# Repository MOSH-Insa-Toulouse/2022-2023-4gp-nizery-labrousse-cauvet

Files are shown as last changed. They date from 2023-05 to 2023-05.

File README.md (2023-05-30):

# *PROJET CAPTEUR - CG-4127-GAF*

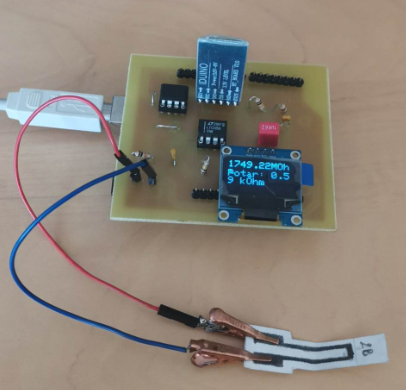
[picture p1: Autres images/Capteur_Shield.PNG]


## Introduction : Description du projet, Cahier des charges et Livrables 

Ce projet s’inscrit dans l’UF “Du capteur au banc de test” de 4ème année de Génie Physique de l’INSA Toulouse. Il s’inscrit dans une démarche low-tech de développement d’un capteur de contrainte et d’un système de mesure permettant la caractérisation du capteur. Il s’appuie sur l’étude de capteurs de contrainte en graphite (système granulaire) dont la résistance varie suivant la déformation du capteur (Pencil Drawn Strain Gauges and Chemiresistors on Paper Cheng-Wei Lin*, Zhibo Zhao*, Jaemyung Kim & Jiaxing Huang Department of Materials Science and Engineering, Northwestern University 2220 Campus Drive, Evanston, IL, 60208, USA).  
Ce travail comprend le design et la fabrication d’un shield Arduino incluant le capteur graphite couplé à un circuit analogique communiquant via un microcontrôleur à une application Android.
Dans un premier temps, nous avons simulé le comportement du circuit analogique sur le logiciel LTSpice. Ce circuit a le double rôle d’amplifier (via un amplificateur transimpédance) et de filtrer le signal délivré par le capteur.  
Ensuite, nous avons réalisé un code Arduino permettant la mesure de résistance et le contrôle des différents éléments du circuit (écran OLED, module Bluetooth et potentiomètre digital). Nous avons préalablement testé notre circuit et le code en montant les différents éléments sur une breadboard, puis nous avons designé un PCB grâce au logiciel KiCad constituant le shield se fixant sur une carte Arduino UNO.  
Après tirage du PCB, nous avons soudé l’ensemble des composants du circuit et développé une application Android sur le site MIT App Inventor affichant les mesures de résistance via transmission Bluetooth.  
Enfin, nous avons réalisé une datasheet caractérisant le capteur pour différents types de crayons graphites en mesurant la variation de résistance relative en fonction de la déformation du capteur grâce à un banc de mesure existant fabriqué en impression 3D.

### Livrables

Les livrables pour ce projet sont :

* Un shield PCB se fixant à une carte Arduino UNO comprenant un amplificateur transimpédance, un module Bluetooth, un écran OLED et un potentiomètre digital.
* Un code Arduino gérant la mesure de résistance du capteur graphite, la communication avec le module Bluetooth, l'affichage à l'écran OLED et la gestion du potentiomètre digital.
* Un Android APK qui gère l'interfaçage du système de mesure sur un téléphone Android.
* La datasheet du capteur de contrainte graphite.

## Matériel nécessaire
* 1 carte Arduino Uno
* 2 Résistance de 100kΩ
* 1 Résistance de 1kΩ
* 1 Potentiomètre digital MCP-41050
* 2 Condensateurs 100nF
* 1 Condensateurs 1µF
* 1 AOP LTC1050
* 1 Écran OLED01
* 1 Module Bluetooth HC-05

## Simulation du circuit transimpédance avec le logiciel LTSpice 

Nous avons réalisé la simulation électrique du circuit associé au shield sur le logiciel LTSpice. Voici le schéma du circuit simulé : 

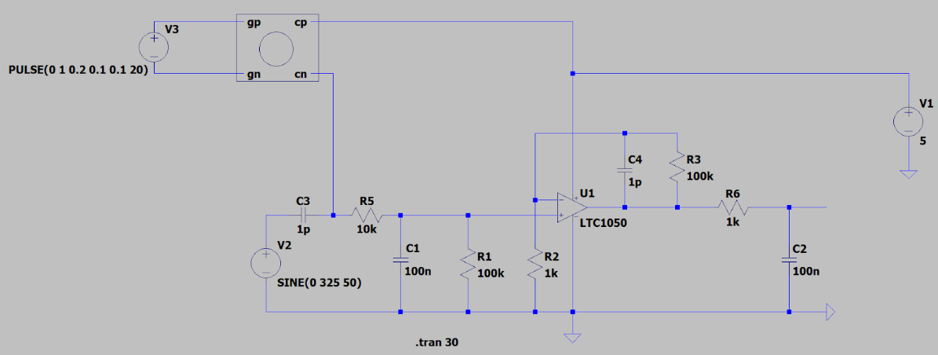
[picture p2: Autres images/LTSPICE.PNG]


Le capteur de graphite délivre un courant de 100 nA qui représente un signal trop faible pour que le microcontrôleur de la carte Arduino détecte les variations du signal. L’amplificateur transimpédance permet donc de transformer le signal de courant en tension et de l’amplifier. Le circuit est ensuite constitué de divers filtres permettant d’atténuer le bruit lié à l'environnement de la mesure (50Hz, hautes fréquences…).
Plusieurs tests ont été effectués sur le circuit et sur les filtres pour connaître le rôle de chacun d’eux et vérifier sa compatibilité avec la carte Arduino qui gère l’acquisition des données.

## Code arduino

Le code .ino donne les instructions à l’arduino pour traiter les informations reçues par le capteur graphite et pour envoyer les informations au module bluetooth HC-05 qui communique avec l’application APK, au potentiomètre digital ainsi qu’à l’écran OLED. Différentes bibliothèques sont incluses, la bibliothèque Adafruit_SSD1306 permet de faciliter la communication avec l’écran OLED, la bibliothèque SPI nous permet d’écrire au potentiomètre digital ses nouvelles valeurs au besoin, SoftwareSerial gère la communication avec l’appareil bluetooth HC-05. Le code de l’arduino permet donc plusieurs choses : 
* Calculer la résistance du capteur graphite en temps réel
* Modifier la valeur de la résistance du potentiomètre digital, ce qui nous permet de régler la sensibilité de la mesure, ainsi que de capter des signaux dans l’intervalle de bits [0:1023] dans lequel l’arduino est limité.
* Afficher la résistance du capteur graphite et la résistance du potentiomètre digital sur l’écran OLED
* Communiquer à l’application la valeur en bits du signal du capteur graphite en compressant sa valeur sur un byte, qui pourra être analysé par l’application APK.

## Création du PCB sur Kicad 

Cette partie du projet consistait à concevoir le PCB du circuit transimpédance sur le logiciel Kicad. En partant d’un template d’une carte Arduino Uno, il a fallu : 
* Concevoir la schématique du circuit transimpédance en créant des symboles pour les composants non existants dans la base de donnée du logiciel
* Concevoir les empreintes réelles de ces composants non existants en prenant en compte leurs caractéristiques physiques (nombres de pins, distance entre les pins, géométrie des empreintes…)
* Effectuer le routage du circuit à partir du chevelu implémenté grâce à la vue schématique du circuit
* Poser le plan de masse pour référencer les pistes au GND

Vous trouverez ci-dessous l’intégralité des symboles et empreintes créées ainsi que la vue schématique du circuit et le PCB final.

### Symboles et empreintes 

* Module Bluetooth HC-05

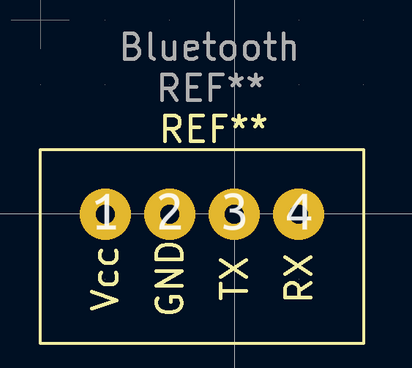
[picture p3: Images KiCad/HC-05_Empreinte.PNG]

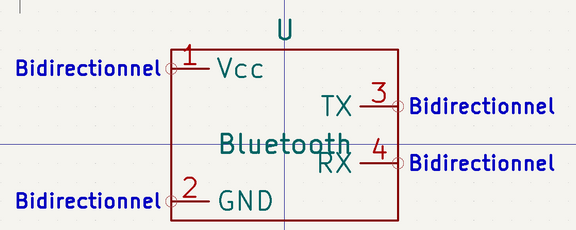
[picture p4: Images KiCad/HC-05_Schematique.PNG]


* Amplificateur LTC1050

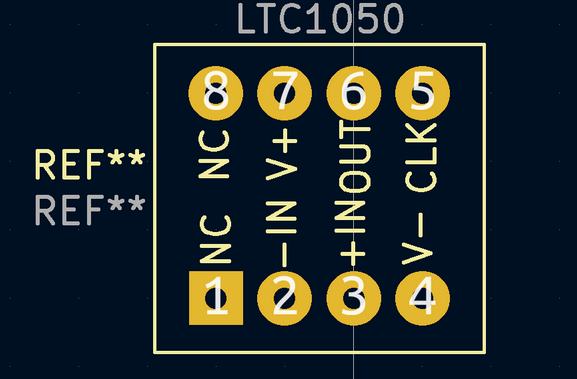
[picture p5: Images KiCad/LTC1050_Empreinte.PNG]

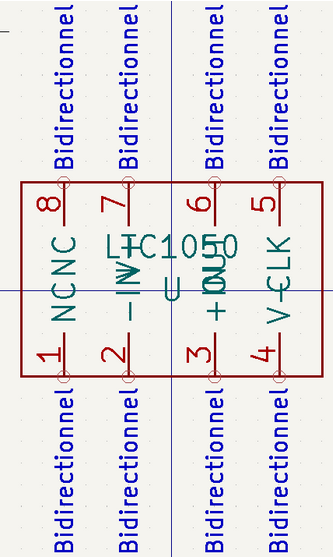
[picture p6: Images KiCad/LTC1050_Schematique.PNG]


* Ecran OLED

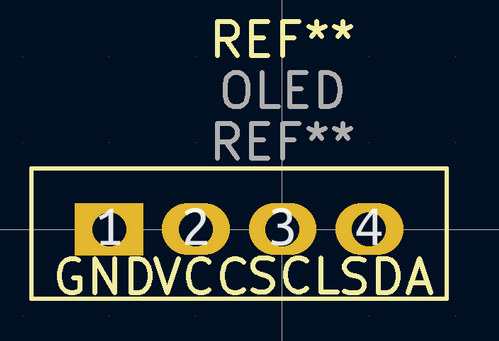
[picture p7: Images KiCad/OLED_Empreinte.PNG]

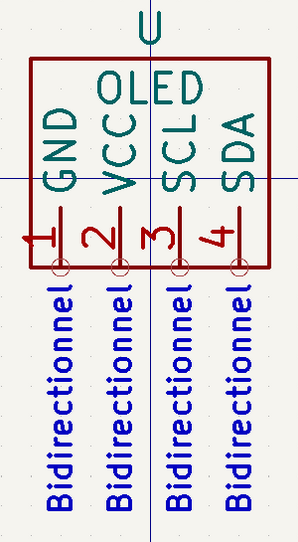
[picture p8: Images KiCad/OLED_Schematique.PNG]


* Potentiomètre digital MCP41050

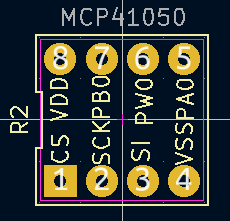
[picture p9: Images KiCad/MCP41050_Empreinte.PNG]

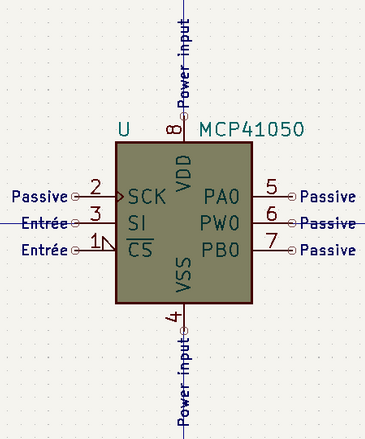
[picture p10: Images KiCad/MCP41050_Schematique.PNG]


### Schéma Complet

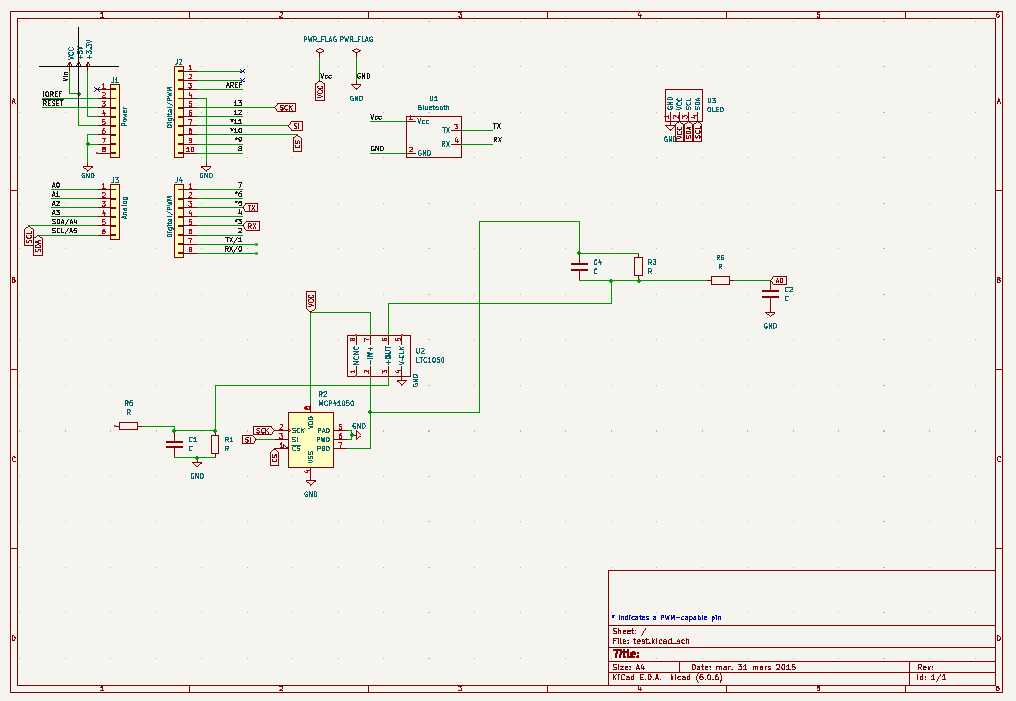
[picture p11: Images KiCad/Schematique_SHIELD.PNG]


### PCB

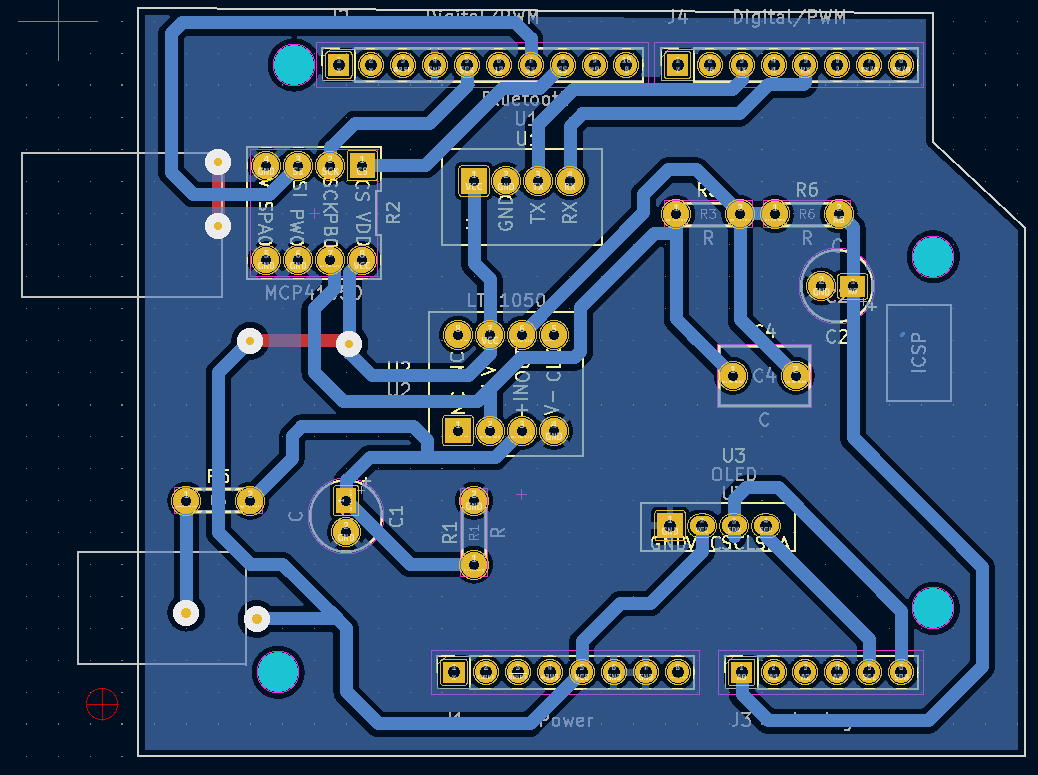
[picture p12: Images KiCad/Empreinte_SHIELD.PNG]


## Fabrication du Shield
 
### Réalisation PCB

Voici ci-dessus le circuit imprimé réalisé à partir d’un calque de PCB. 

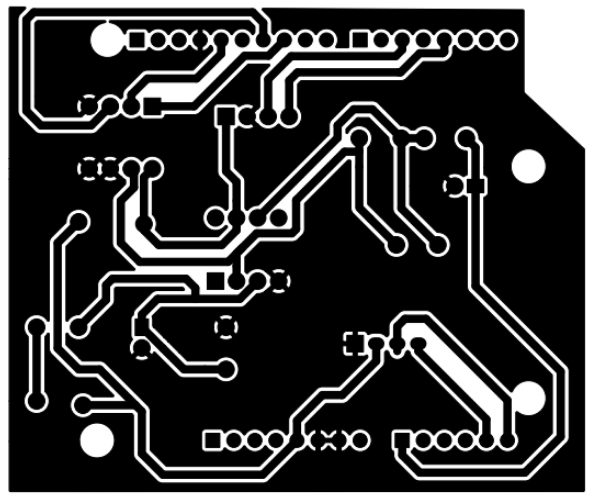
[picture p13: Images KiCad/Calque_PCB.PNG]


Le PCB a été réalisé au sein de deux départements de l’INSA Toulouse, le Génie Électrique et Informatique et le Génie Physique. Il a été fabriqué avec une plaquette d’époxy recouverte d’une couche de cuivre d’environ 60𝝻m. Nous avons imprimé sur du calque le circuit ci-dessus, puis nous avons insolé aux UVs notre plaquette avec ce calque pendant une dizaine de minutes. Après avoir retiré la partie de résine non isolée avec un révélateur, nous avons plongé notre plaquette dans un bain de percholorure de fer. Cela a permis de retirer le cuivre qui n’était pas protégé et de révéler les pistes de notre circuit.

### Perçage et soudures 

Une fois le PCB réalisé, il faut percer avec une perceuse électrique les trous pour y mettre les différents composants. Nous avons utilisé deux tailles de pointes pour percer les trous:
un de diamètre 0,8mm pour tous les différents composants et headers des modules OLED et Bluetooth
un de diamètre 1mm pour les broches de connexion de la carte Arduino Uno

Nous avons aussi dû percer deux trous pour y insérer un via pour relier deux points de masse (cela était prévu dans le schéma Kicad).

## Application téléphone APK

Nous avons développé une application Android à l’aide du site MIT App Inventor. Cette application permet de recevoir les données de la carte Arduino par connexion Bluetooth avec le module HC-05 implémenté sur le shield de la carte Arduino. Après connexion Bluetooth, un graphe se dessine permettant de suivre la résistance du capteur graphite en fonction du temps et des contraintes qui lui sont appliquées. La valeur de cette résistance est également affichée implicitement en plus de la valeur de la de résistance du potentiomètre digital.

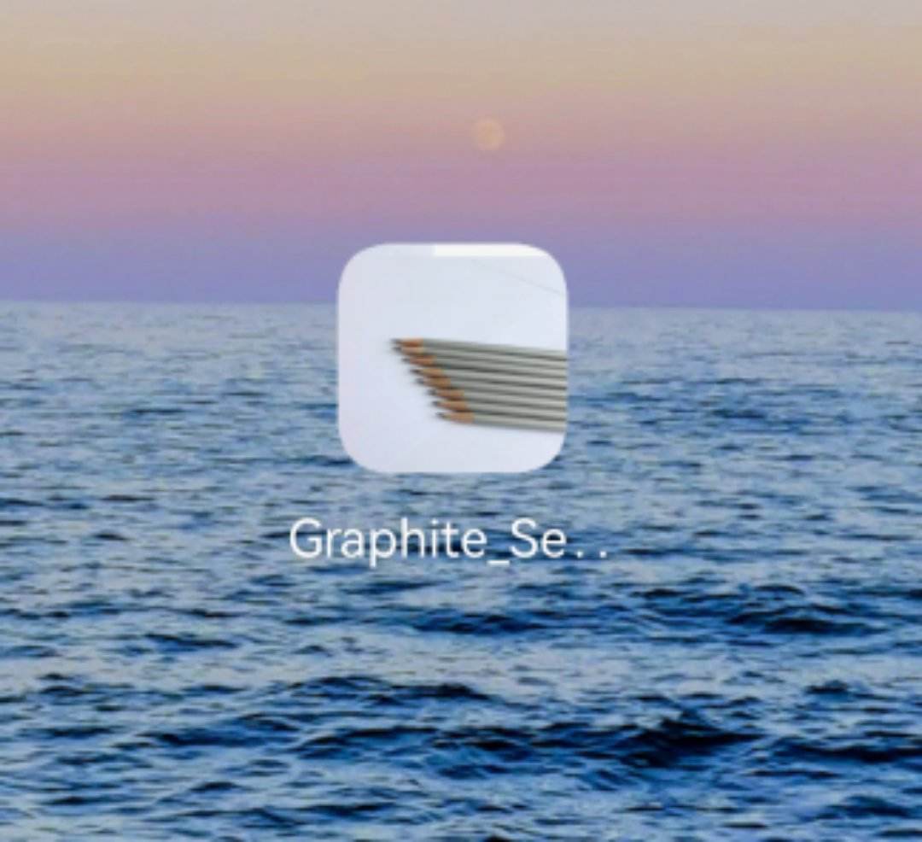
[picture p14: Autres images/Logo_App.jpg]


## Banc de test  

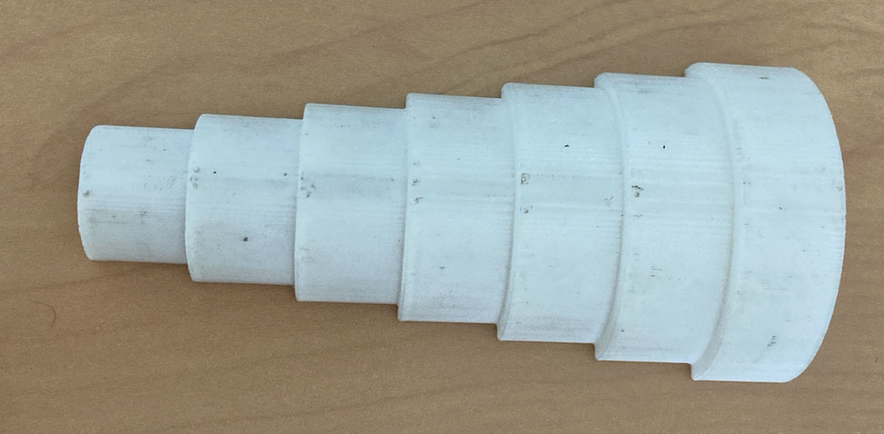
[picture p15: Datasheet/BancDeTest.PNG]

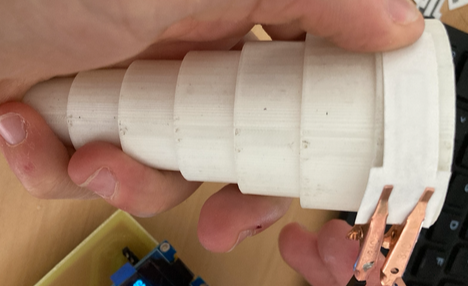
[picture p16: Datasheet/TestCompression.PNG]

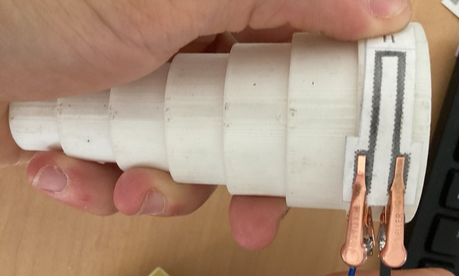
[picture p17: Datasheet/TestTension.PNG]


Nous utilisons ce banc de test composé de 7 demi cylindres de différents diamètres allant de 2 à 5 cm avec un pax de 0,5 cm. Nous posons le capteur sur chacun des cylindres et appliquons donc une déformation  sur celui-ci. Cette déformation se retrouve avec la formule ci-dessous : 
$$\epsilon = \frac{e}{2r}$$ 
avec e l’épaisseur du capteur et r le rayon de courbure donc le rayon de chaque demi cylindre.
Nous avons réalisé les mesures en compression et en tension pour chacun de nos capteurs.  

### Résultats obtenus

Vous retrouverez les résultats obtenus avec notre banc de test dans la datasheet [ici](Datasheet/Datasheet_CG-4127-GAF.docx).

### Analyse et pistes d’améliorations

Lors de nos mesures, nous devions reprendre le R0 à chaque essai car celui-ci augmentait entre-temps. Le papier trop fragile, s'abîmait et rendait plus difficile la conduction des électrons, la résistance augmente donc. Il serait donc envisageable de prendre un papier plus résistant qui ne se déformerait pas de manière permanente après chaque mesure.

On peut également penser à l'utilisation d'un dispositif à base d'un servomoteur, en remplacement de notre banc de test, car celui-ci nous permettrait de reproduire les expériences de manière plus fiable, avec tout le temps la même tension/compression exercée entre les différents capteurs.

Afin d'avoir une excellente sensibilité pour toutes les plages de résistance, on aurait pu augmenter le nombre de valeurs de résistance du potentiomètre qui se règlent automatiquement.

## Datasheet 

La datasheet de notre capteur est disponible dans le dossier Datasheet [ici](Datasheet/Datasheet_CG-4127-GAF.docx).

## *Auteurs*

Si vous avez des remarques ou questions complémentaires sur ce projet, n’hésitez pas à nous contacter :

Guillaume Cauvet : cauvet@insa-toulouse.fr  
Fabien Labrousse : labrousse@insa-toulouse.fr  
Audrey Nizery : nizery@insa-toulouse.fr

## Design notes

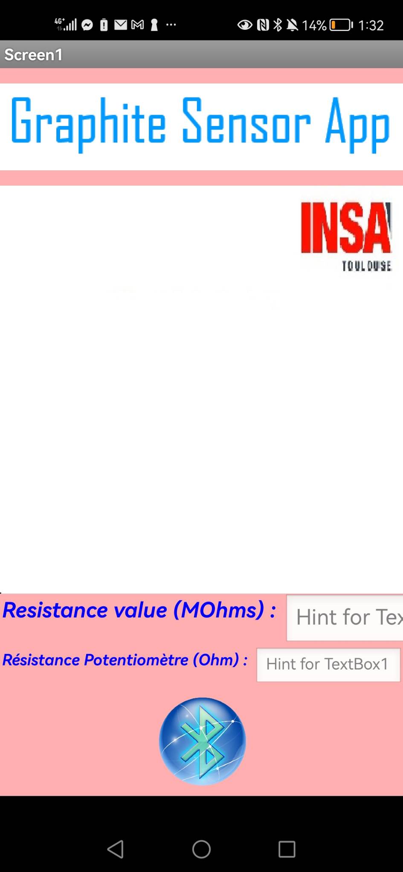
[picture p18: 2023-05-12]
APK Bluetooth/App_BT_CG-4127-GAF.jpg

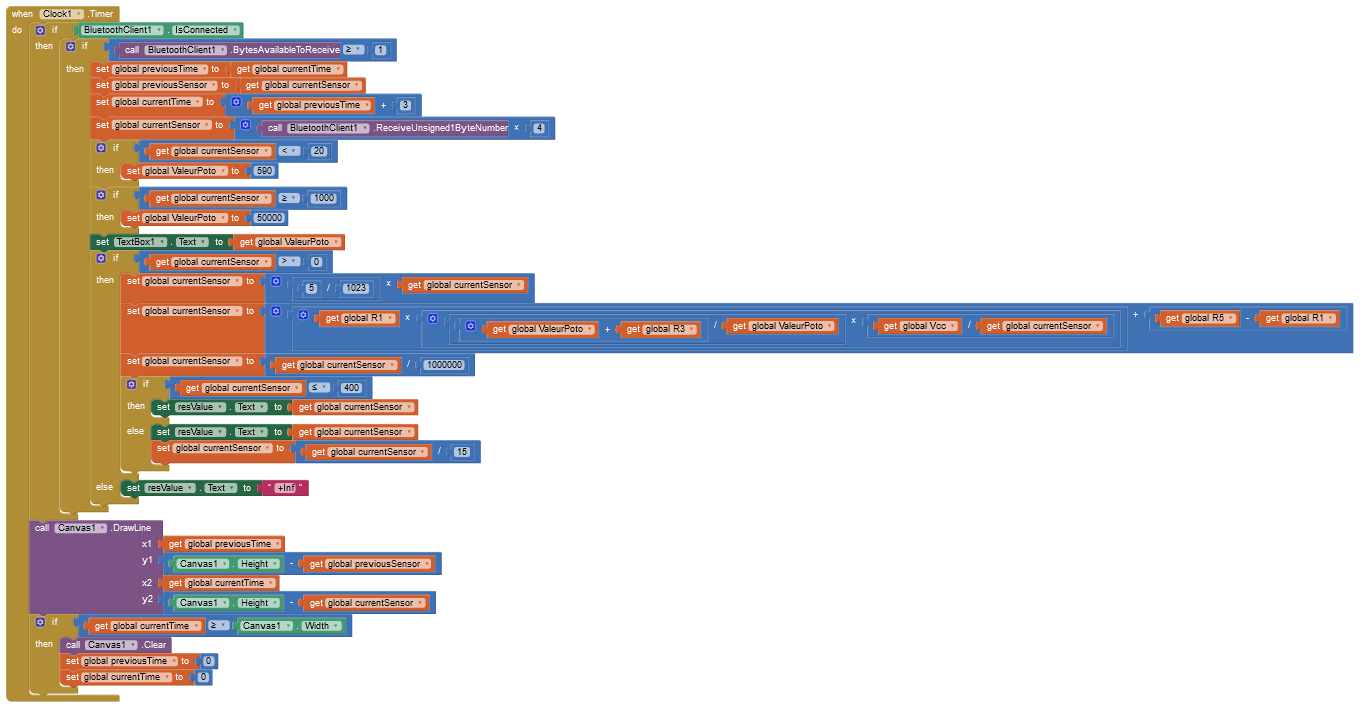
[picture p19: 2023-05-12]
APK Bluetooth/Code_Bluetooth_Part2.PNG

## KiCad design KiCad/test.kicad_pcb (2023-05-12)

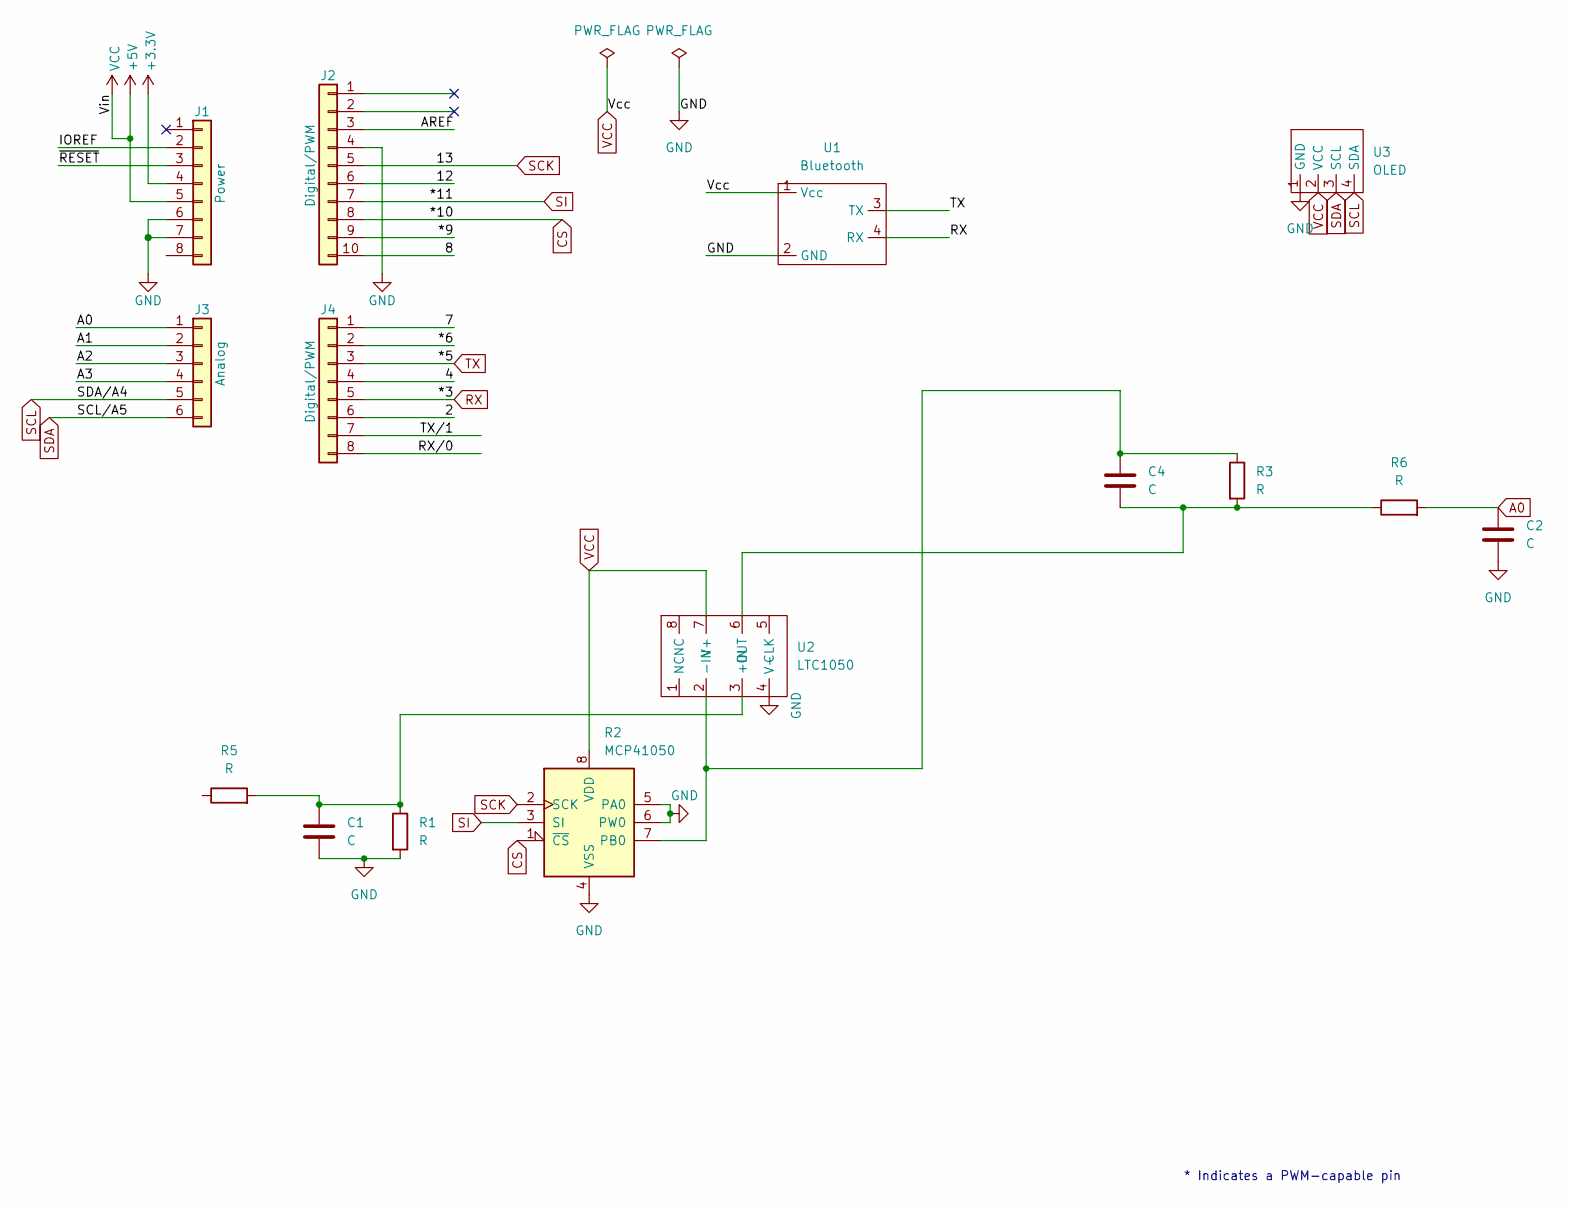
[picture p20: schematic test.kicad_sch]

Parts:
C1, C2: C; CP_Radial_Tantal_D5.5mm_P2.50mm
C4: C; C_Rect_L7.0mm_W4.5mm_P5.00mm
J1: Power; PinSocket_1x08_P2.54mm_Vertical
J2: Digital/PWM; PinSocket_1x10_P2.54mm_Vertical
J3: Analog; PinSocket_1x06_P2.54mm_Vertical
J4: Digital/PWM; PinSocket_1x08_P2.54mm_Vertical
R1, R3, R5, R6: R; R_Axial_DIN0204_L3.6mm_D1.6mm_P5.08mm_Horizontal
R2: MCP41050; Pot_Digital
U1: Bluetooth
U2: LTC1050
U3: OLED

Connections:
+3V3: J1.4
/2: J4.6
/4: J4.4
/7: J4.1
/8: J2.10
/12: J2.6
/*6: J4.2
/*9: J2.9
/A1: J3.2
/A2: J3.3
/A3: J3.4
/AREF: J2.3
/IOREF: J1.2
/RX/0: J4.8
/TX/1: J4.7
/~RESET: J1.3
A0: C2.1, J3.1, R6.2
CS: J2.8, R2.1 (~CS)
GND: C1.2, C2.2, J1.6, J1.7, J2.4, R1.2, R2.4 (VSS), R2.5 (PA0), R2.6 (PW0), U1.2 (GND), U2.4 (V-), U3.1 (GND)
unnamed: C1.1, R1.1, R5.2, U2.3 (+IN)
unnamed: C4.1, R2.7 (PB0), R3.1, U2.2 (-IN)
unnamed: C4.2, R3.2, R6.1, U2.6 (OUT)
RX: J4.5, U1.4 (RX)
SCK: J2.5, R2.2 (SCK)
SCL: J3.5, U3.4 (SDA)
SDA: J3.6, U3.3 (SCL)
SI: J2.7, R2.3 (SI)
TX: J4.3, U1.3 (TX)
VCC: J1.5, R2.8 (VDD), U1.1 (Vcc), U2.7 (V+), U3.2 (VCC)

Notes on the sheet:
* Indicates a PWM-capable pin

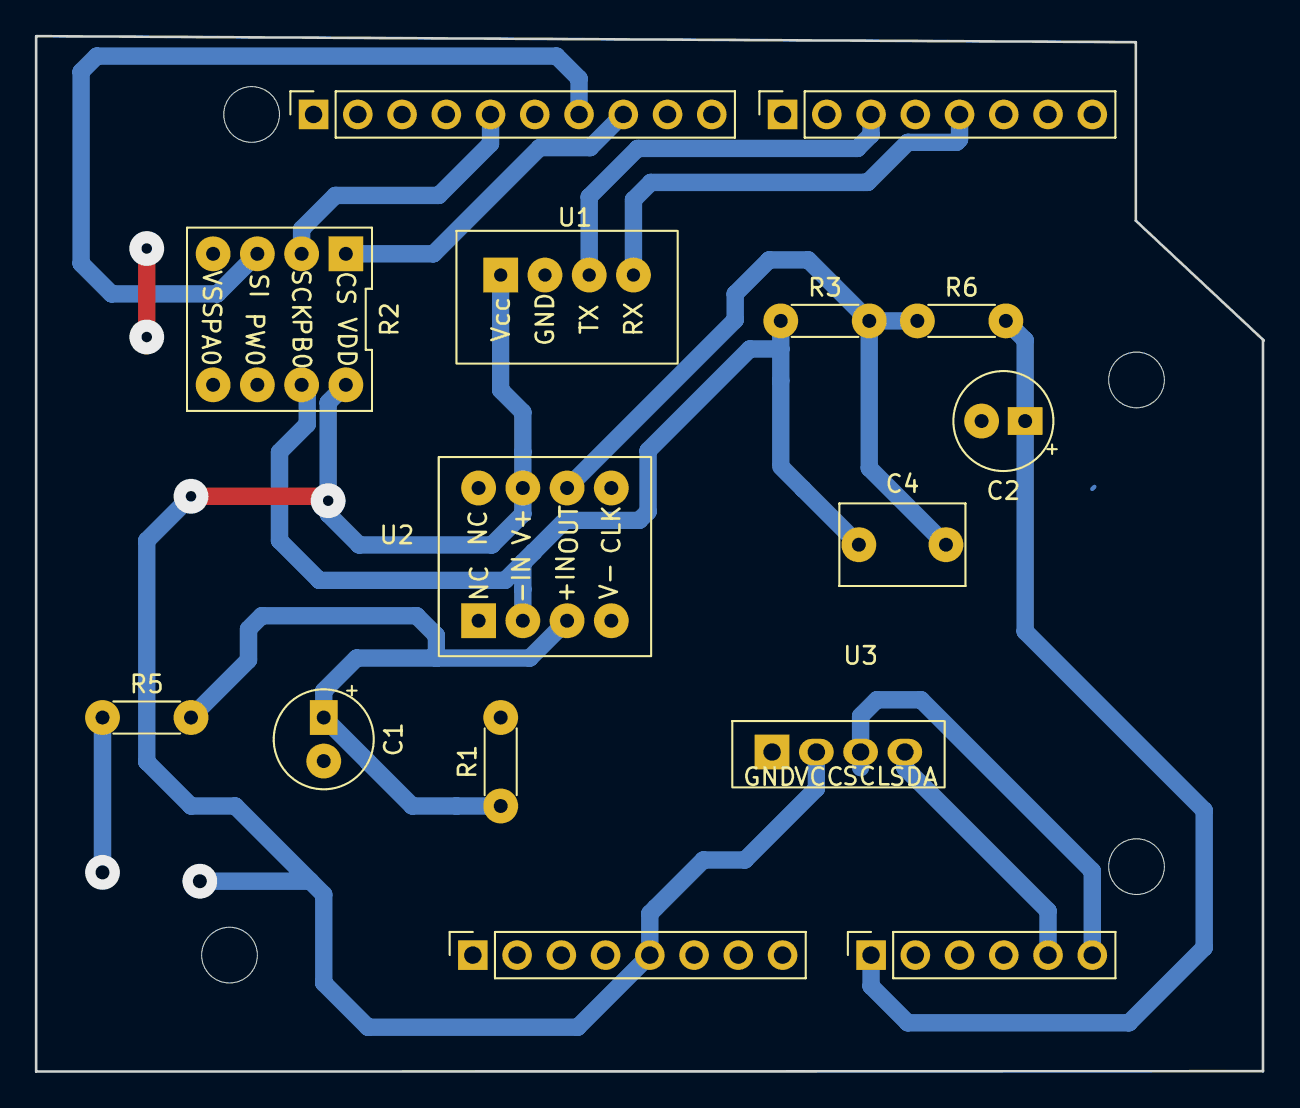
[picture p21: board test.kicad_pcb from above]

Board: 2 copper layers, 70.5 x 59.4 mm, 19 parts (0 on the bottom side), 13 nets.

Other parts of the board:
MH1, MH2, MH3, MH4: MountingHole_3.2mm

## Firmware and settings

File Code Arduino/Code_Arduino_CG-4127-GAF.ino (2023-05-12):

/////////////////// INCLUSION DES BIBLIOTHEQUES /////////////////////////

#include <Adafruit_SSD1306.h>               // Bibliothèque de l'écran OLED
#include <SPI.h>                            // Bibliothèque pour communiquer avec le potentiomètre digital
#include <SoftwareSerial.h>                 // Bibliothèque pour gérer la communication avec l'appareil bluetooth

/////////////////// DEFINITION DE PARAMETRES //////////////////////////

#define nombreDePixelsEnLargeur 128         // Taille de l'écran OLED, en pixel, au niveau de sa largeur
#define nombreDePixelsEnHauteur 64          // Taille de l'écran OLED, en pixel, au niveau de sa hauteur
#define brocheResetOLED         -1          // Reset de l'OLED partagé avec l'Arduino (d'où la valeur à -1, et non un numéro de pin)
#define adresseI2CecranOLED     0x3C        // Adresse de "mon" écran OLED sur le bus i2c (généralement égal à 0x3C ou 0x3D)
// Define the MCP41050 OP command bits (only one POT), potentiomètre 50kOhm max
// Note: command byte format xxCCxxPP, CC command, PP pot number (01 if selected) 
#define MCP_NOP 0b00000000
#define MCP_WRITE 0b00010001
#define MCP_SHTDWN 0b00100001
#define rxPin 5 // Broche 11 en tant que RX, raccordé sur TX du HC-05
#define txPin 3 // Broche 10 en tant que RX, raccordé sur TX du HC-05
#define baudrate 9600 // baudRate à 9600, identique à celui du moniteur série pour synchroniser la communication
SoftwareSerial mySerial(rxPin ,txPin); // Définition du software serial

const int ssMCPin = 10; // Define the slave select for the digital pot

Adafruit_SSD1306 ecranOLED(nombreDePixelsEnLargeur, nombreDePixelsEnHauteur, &Wire, brocheResetOLED); // On nomme ecranOLED la bibliothèque Adafruit pour
// gérer par la suite les commandes de l'écran OLED

////////////// DECLARATION DES VARIABLES /////////////////////////

const int Capteur = A0; // On initialise le capteur à l'entrée analogique A0
int ValeurResBit=80; // valeur de la résistance comprise entre 0 et 1023 bits
//uint8_t ValeurResbitAppli;
float ValeurResBitFloat; // Sert uniquement à récupérer la valeur de ResBit en float pour éviter des types avec le calcul de ValeurResTension
float ValeurResTension; // valeur de la résistance comprise entre 0 et 5V
float ValeurRes; // valeur de la résistance du capteur graphite en OhM
float ValeurPotoR2=255; // Le potentiomètre digital divise ses valeurs de résistance entre 0 et 50kOmh en un intervalle de 256 valeurs (sur 256 bits)
float ValeurPotoR2OLED; // valeur de la résistance R2 qu'on utilisera spécifiquement pour afficher la valeur de R2 sur l'écran OLED
float ValeurPotoR2Calculs; // valeur de la résistance R2 qu'on utilise pour les calculs, R2 est en Ohm ici
float R1=100000; //en Ohm
float R3=100000;
float R5=10000;
float R6=1000;
float Vcc=5; //en Volt

/////////////// FONCTION POUR ECRIRE AU POTENTIOMETRE DIGITAL ///////////////////////////////

void SPIWrite(uint8_t cmd, uint8_t data, uint8_t ssPin) // SPI write the command and data to the MCP IC connected to the ssPin, on s'en sert pour communiquer
//avec le potentiomètre digital
{
  SPI.beginTransaction(SPISettings(14000000, MSBFIRST, SPI_MODE0)); //https://www.arduino.cc/en/Reference/SPISettings
  data = constrain (data, 0, 255); //comme cette fonction sert à communiquer avec le potentiomètre digital qui est sur 256 bits, on restreint les valeurs
  //de la donnée entre 0 et 255, un intervalle entier de 256 valeurs, celles que peut prendre le potentiomètre digital
  digitalWrite(ssPin, LOW); // SS pin low to select chip
  
  SPI.transfer(cmd);        // Send command code
  SPI.transfer(data);       // Send associated value
  
  digitalWrite(ssPin, HIGH);// SS pin high to de-select chip
  SPI.endTransaction(); //à l'issu de toutes ces étapes, on termine la communication des données
}

///////////////////////// SETUP DU PROGRAMME ////////////////////////////////

void setup() {
  if(!ecranOLED.begin(SSD1306_SWITCHCAPVCC, adresseI2CecranOLED)) // On initialise l'écran OLED et on le prépare à communiquer dans le voidLoop
   while(1);   
  ecranOLED.clearDisplay(); // On clear l'écran avant de rentrer dans le corps du code
  pinMode(rxPin,INPUT); // On définit le pin Rx en INPUT
  pinMode(txPin,OUTPUT); // On définit le pin Tx en OUTPUT
  mySerial.begin(baudrate); // On définit le baudrate de la communication avec l'appareil bluetooth à 9600
  pinMode(Capteur,INPUT); // On définit l'entrée analogique A0 en INPUT, c'est celle qui va recevoir les valeurs de la résistance du capteur graphite
  pinMode (ssMCPin, OUTPUT); //select pin output
  digitalWrite(ssMCPin, HIGH); //SPI chip disabled
  SPI.begin();  
  Serial.begin(9600);
  Serial.println(F("[MCP Digital Pot Test]")); //print to serial
  SPIWrite(MCP_WRITE, ValeurPotoR2, ssMCPin);
}

/////////////////////////// CORPS DU CODE //////////////////////////////////////////

void loop() {
    uint8_t ValeurResBitAppli;
    ValeurResBit=analogRead(Capteur);
    //SPIWrite(MCP_WRITE, ValeurPotoR2, ssMCPin); // On envoie la valeur au potentiomètre digital, 50kOhm pour la première mesure, voir 2 lignes après pour les nouvelles valeurs
    //ValeurResBit=analogRead(Capteur); // On lit la valeur sur l'entree analogique A0, celle du capteur donc, on obtient une valeur entre 0 et 1023, c'est celle qu'on enverra à l'appli via le bluetooth, c'est un int codé sur peut de bits donc moins lourd pour l'envoie des données contrairement à celui en float qui sert pour les calculs
    if (ValeurResBit<20){ // Si la valeur est inférieure à 30, celà veut dire qu'on se rapproche de la limite inférieure (0) et il est donc nécessaire de réajuster la valeur du potentiomètre digital en conséquence. On a ValeurResBit faible pour des résistances très élevées
      ValeurPotoR2=3; // On diminue R2 de beaucoup pour amplifier le signal et recevoir une valeur supérieure à 0
      SPIWrite(MCP_WRITE, ValeurPotoR2, ssMCPin); // On envoie la valeur
    }
    else if (ValeurResBit>1000){ // On utilise cette condition pour des résistances de l'ordre de la centaine de MOhm environ
      ValeurPotoR2=255; // On choisit une valeur de résistance intermédiaire
      SPIWrite(MCP_WRITE, ValeurPotoR2, ssMCPin); // On envoie la valeur
    }
    ValeurResBit=analogRead(Capteur);
    ValeurResBitAppli=ValeurResBit/4;
    Serial.println(ValeurResBitAppli); // Test pour vérifier la valeur mesurer à la sortie de A0 en cass de problèmes avec l'appli; ligne à vocation uniquement utilitaire pour le programmeur
    ValeurResBitFloat=analogRead(Capteur); // Valeur à la sortie de A0, float qui servira pour les calculs, valeur en float pour éviter les conflits avec le type de ValeurResTension
    mySerial.write(ValeurResBitAppli); // On envoie à l'appareil bluetooth, qui communiquera avec l'appli, la valeur à la sortie de A0
    ValeurResTension=ValeurResBitFloat*5/1023; // On convertit le signal à la sortie de A0 en tension; l'arduino ne peut recevoir des tensions que jusqu'à 5V max
    ValeurPotoR2Calculs=ValeurPotoR2*50000/255; // On convertit la valeur de R2 (le potentiomètre digital) échelonné de 0 à 255, en Ohm pour les calculs, 255 correspondant à 50 kOhm
    ValeurRes=(R1*((ValeurPotoR2Calculs+R3)/ValeurPotoR2Calculs)*Vcc/ValeurResTension)-R5-R1; // Valeur exacte de la résistance en fonction des autres composants du circuit
    ValeurRes=ValeurRes/1000000; //en MOhm
    ValeurPotoR2OLED=ValeurPotoR2Calculs/1000; // R2 en kOhm
    
    Serial.println(ValeurRes); // On affiche sur le moniteur série la valeur de la résistance, à plus un intérêt pour le programmeur qui veut s'assurer de la justesse de ses résultats
    delay(200);   // On met un délai de 200ms pour éviter que l'écra/l'arduino ne soit surchargés de données et n'arrivent plus à suivre le traitement des informations
                                       
    ecranOLED.clearDisplay(); // Effaçage de l'intégralité du buffer
    ecranOLED.setTextSize(2); // Taille des caractères (1:1, puis 2:1, puis 3:1)
    ecranOLED.setTextColor(SSD1306_WHITE); // On choisit la couleur du texte sur l'écran OLED
    ecranOLED.setCursor(0, 0); // Déplacement du curseur en position (0,0), c'est à dire dans l'angle supérieur gauche
    ecranOLED.print(ValeurRes); // On affiche la valeur de la résistance en MOhm sur l'écran OLED
    ecranOLED.print("MOhm"); // Texte affiché sur l'OLED pour préciser que la résistance du capteur est en MOhm
    ecranOLED.setCursor(0, 20); // On déplace le curseur de l'acran plus bas pour écirre une nouvelle ligne de texte
    ecranOLED.print("Potar: "); // On va écrire la valeur de la résistance du potentiomètre...
    ecranOLED.print(ValeurPotoR2OLED); //... On l'écrit...
    ecranOLED.print(" kOhm"); // ... Et on précise que c'est en kOhm
    ecranOLED.display(); // Transfert le buffer à l'écran
    
  }
